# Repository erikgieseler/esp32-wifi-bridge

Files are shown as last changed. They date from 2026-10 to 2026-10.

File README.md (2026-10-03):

# ESP32-S3-POE-ETH WiFi–Ethernet SSL Bridge

Bridges your LAN to a Tesla Powerwall’s isolated Wi-Fi AP. Encrypted TLS is forwarded as-is (no decryption). TTL is set to 64 so the Powerwall sees local traffic.

Architecture

**Ethernet `:443`** — Powerwall passthrough (no login).  
**Ethernet `:80`** — dashboard (HTML login, username `admin`).  
Neither port is bound on the Tesla Wi-Fi address.

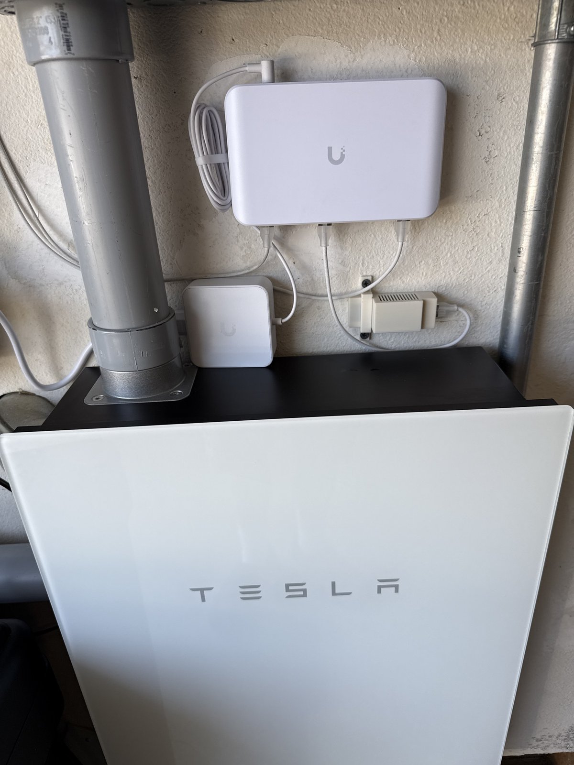
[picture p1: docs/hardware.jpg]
Installed next to a Tesla Powerwall


## Install

Browser flash (Chrome, Edge, or Opera) from GitHub Pages:

**https://erikgieseler.github.io/esp32-wifi-bridge/**

USB to the board, click **Install**. Tagged CI publishes `firmware.bin` and `version.json` there. Remote OTA uses the same URL. Enable **Settings → Pages → Deploy from a branch → `gh-pages`**. Forks do not need `config.local.h`.

After flash:

1. Plug Ethernet (PoE or USB power).
2. Open `http://powerwall.local/` or `http://<ethernet-ip>/`.
3. Set the admin password (first boot).
4. Save the Powerwall Wi-Fi SSID/password.
5. Optional: Ethernet tile → static IP.

Locked out: hold **BOOT 15 seconds** — forces DHCP and clears the admin password.

## Dashboard

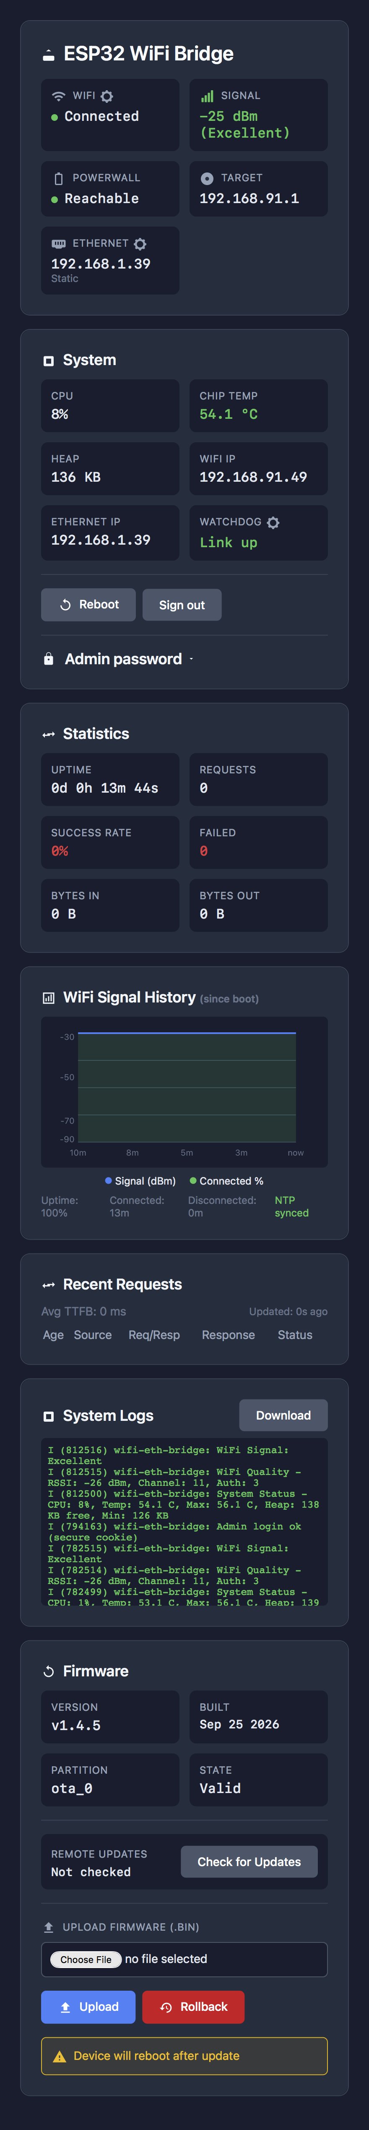
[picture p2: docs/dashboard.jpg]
Dashboard


- Wi-Fi RSSI and 24 h chart, Powerwall reachability
- Ethernet DHCP or static (click the Ethernet tile)
- CPU, chip temp, heap, uptime, proxy stats
- HTML login + 7-day session cookie (re-login after reboot/OTA)
- Download logs (last 200 lines, HAProxy `httpd*` noise omitted)
- Local upload or GitHub remote OTA

Put the dashboard behind TLS if you want HTTPS: HAProxy (or similar) to `:80`. Health checks should `GET /health` and expect **200**. Do not send a password; `/health` is unauthenticated on purpose.

## Hardware

| | |
|---|---|
| Board | Waveshare ESP32-S3-POE-ETH |
| PHY | W5500 over SPI |
| Framework | ESP-IDF (PlatformIO `espressif32@6.9.0`) |

| SPI | GPIO |
|---|---|
| MISO | 12 |
| MOSI | 11 |
| SCLK | 13 |
| CS | 14 |
| INT | 10 |
| BOOT (hold 15 s) | 0 |

### Printed case

A snap-fit ASA enclosure (no supports) with a wall mount is in [`case/`](case/). Vents are meant for **horizontal** wall install so heat rises through the grille.

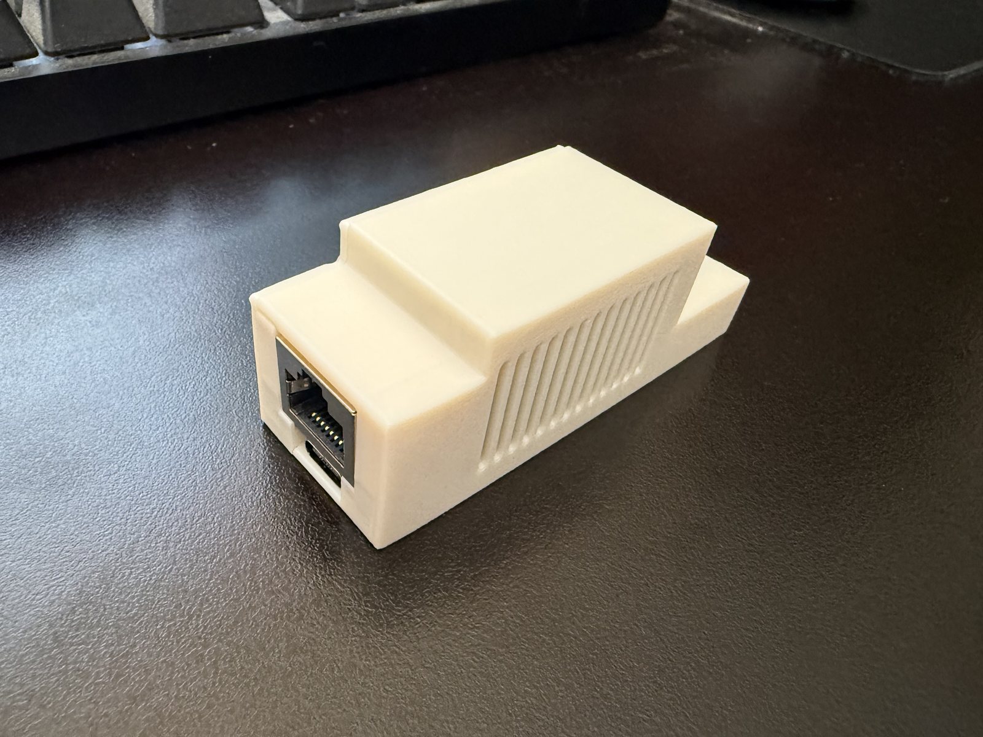
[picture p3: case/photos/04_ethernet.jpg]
Case


## Features

- SSL/TLS **passthrough** to `192.168.91.1:443` with **TTL 64**
- Ethernet **DHCP** or **static IP** (NVS); 45 s gateway-unreachable fallback to DHCP (saved static kept)
- HTTP and proxy **bound to the Ethernet IP only**
- mDNS `powerwall.local` (`_powerwall._tcp` :443, `_http._tcp` :80)
- Admin password: salted SHA-256 in NVS, HTML form, session cookie (`HttpOnly; SameSite=Lax`; `Secure` when `X-Forwarded-Proto: https`)
- Watchdog with two triggers (see below). Default is unchanged.
- NTP over Ethernet, OTA from GitHub Pages, Ethernet DNS snapshot so Wi-Fi cannot steal OTA DNS

## Reverse proxy (HAProxy)

```
backend esp32
    server esp32 192.168.1.39:80
    option httpchk
    http-check send meth GET uri /health
    http-check expect status 200
```

Send `X-Forwarded-Proto: https` on the TLS frontend so the session cookie is marked `Secure` (Safari will persist it). Check interval around 15–30 s is plenty.

## HTTP

Dashboard: `http://powerwall.local/` or `http://<eth-ip>/`  
First boot: set password. Later: **Username — admin**. Port 443 is not this login.

| Path | Auth | Notes |
|---|---|---|
| `GET /` | session | Dashboard |
| `GET/POST /login` | no | HTML login |
| `GET /logout` | no | Clears cookie |
| `GET /health` | no | `200 ok` for load balancers |
| `GET /logs.txt` | session | Downloadable log dump |
| `GET /api/status` | session | JSON (wifi, eth, temp, heap, watchdog) |
| `GET /api/requests` | session | Recent proxy requests |
| `GET /api/logs` | session | JSON log ring |
| `GET /api/wifi-history` | session | 24 h RSSI buckets |
| `GET /api/update` | session | Remote OTA status |
| `POST /api/check-update` | session | Check GitHub |
| `POST /api/install-update` | session | Install from GitHub |
| `GET /wifi/scan` | session | Scan SSIDs |
| `POST /wifi/save` | session | Save Wi-Fi |
| `POST /eth/save` | session | Save Ethernet (reboots) |
| `POST /watchdog/save` | session | `mode=proxy` or `mode=link` (no reboot) |
| `POST /admin/setup` | first boot | Set password |
| `POST /admin/password` | session | Change password |
| `POST /ota/upload` | session | Upload `.bin` |
| `POST /reboot` | session | Reboot |

Unauthenticated page requests redirect to `/login`. APIs return JSON `401`.

### Ethernet static IP

1. Dashboard → Ethernet tile → Static IP (address, mask, gateway, DNS).
2. Save (reboots).
3. If you lose it: wait ~45 s for DHCP fallback, or hold BOOT 15 s (also clears the admin password).

### Admin password

Stored as salt + SHA-256 in NVS, not in the firmware image. Change it from the System card (collapsed). Reboot/OTA drops RAM sessions; the cookie may still be in the browser until you sign in again.

### Watchdog

Click the **Watchdog** tile on the System card. Pick a trigger and **Save**. The device does not reboot. The choice is stored in NVS, survives OTA, and is not cleared by the 15-second BOOT hold.

| Trigger | When to use it | What it does |
|---|---|---|
| **Proxy clients** (default) | This bridge is the path clients use to reach the Powerwall | Stays **Idle** until the first successful proxy. Then reboots if no client completes a proxy for 10 minutes. |
| **Powerwall link** | Another path on the LAN reaches the gateway and this bridge is only a fallback | Ignores whether anyone is using the proxy. Reboots only if `192.168.91.1:443` stays unreachable for 10 minutes. |

The 10-minute clock in Powerwall link mode does not start until Wi-Fi has associated at least once, so boot is not treated as a failure. Reachability is a short TCP connect to `192.168.91.1:443` every **5 minutes** (not while the dashboard is merely refreshing). The tile keeps the last result. One extra check runs before a reboot, so a link that recovered is not reset by a stale failure. The tile shows **Link up**, or **Link down** with how long it has been down (yellow, then red, as it nears 10 minutes). If the Powerwall is actually off, the bridge will reboot about 10–15 minutes after it stops answering, then every 10 minutes until it answers again. A reboot cannot bring the gateway back. Proxy clients mode is unchanged: no probe unless the dashboard is open, and then about every 5 seconds.

Switching back to **Proxy clients** disarms the watchdog until the next successful proxy, so an old idle stretch does not reboot the device immediately.

## Configuration

Compile-time defaults live in [`include/config.h`](include/config.h). Runtime Wi-Fi, Ethernet IP, watchdog trigger, and the admin password are NVS (dashboard), not git.

OTA URL is derived from the GitHub remote at build time (`https://<owner>.github.io/<repo>/version.json`). Optional gitignored overrides: copy [`include/config.local.h.example`](include/config.local.h.example) to `include/config.local.h`.

```c
#define POWERWALL_IP_STR "192.168.91.1"
#define PROXY_PORT 443
#define PROXY_TIMEOUT_MS 60000
#define TTL_VALUE 64
#define ETH_DHCP_FALLBACK_SEC 45
```

## Build

```bash
pio run                    # build
pio run -t upload          # USB
pio device monitor         # serial
./deploy.sh                # OTA via mDNS
./deploy.sh -i <IP>        # OTA to one IP
```

Tags `v*` build firmware, GitHub Release, and Pages. Flash wear: OTA alternates `ota_0` / `ota_1`; NVS is not rewritten by OTA.

## Layout

| Path | Role |
|---|---|
| `src/main.c` | Ethernet/Wi-Fi, HTTP, auth, watchdog, log ring |
| `src/proxy.c` | TLS passthrough, buffer pool, request log |
| `src/remote_ota.c` | GitHub OTA, Ethernet DNS pin |
| `src/wifi_metrics.c` | NTP + 24 h RSSI history |
| `include/config.h` | Compile-time constants |
| `include/web_ui.h` | CSS / JS / icons |
| `partitions.csv` | nvs 24 KB, dual 1.75 MB OTA slots |
| `case/` | ASA enclosure STLs + print notes |

## License

Provided as-is for ESP32-S3-POE-ETH hardware. Fork of [cwagz/esp32-wifi-bridge](https://github.com/cwagz/esp32-wifi-bridge).

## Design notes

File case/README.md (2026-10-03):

# 3D-printed enclosure

Snap-fit case for the **Waveshare ESP32-S3-POE-ETH** (board + PoE hat). Designed to hang **horizontally** on the wall next to a Tesla Powerwall. Vents are placed so hot air rises and draws cool air through the shell.

ASA, **no supports**.

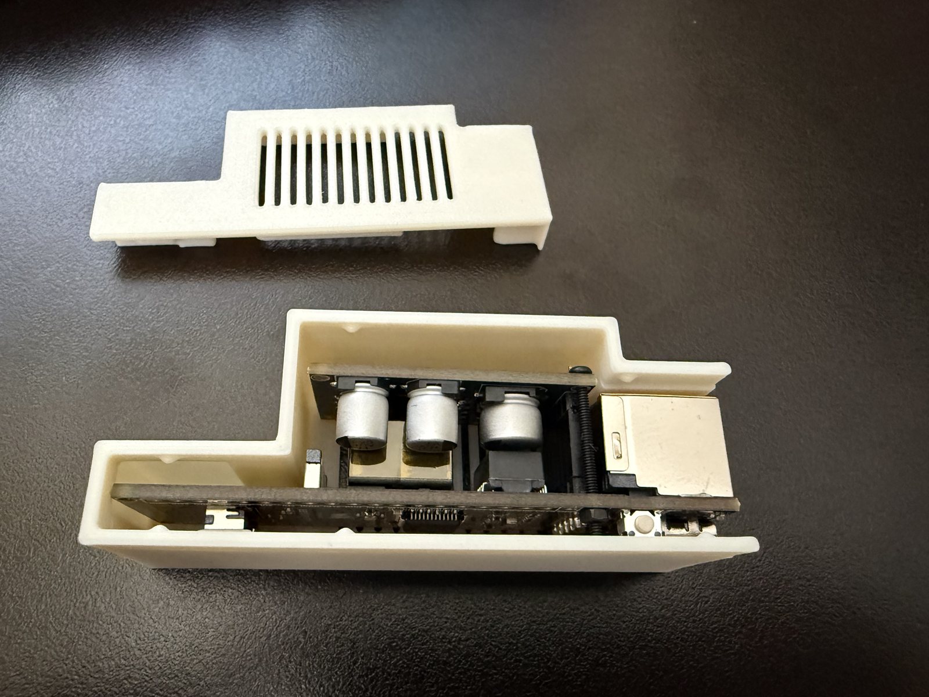
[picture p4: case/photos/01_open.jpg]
Open case with board

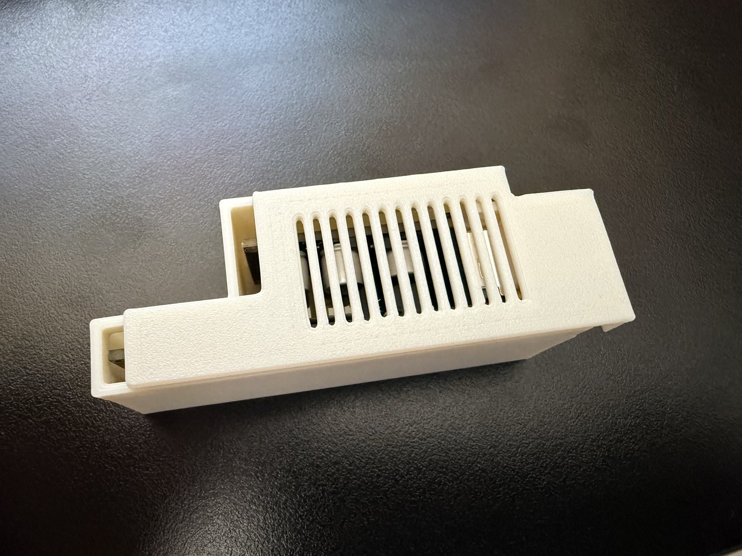
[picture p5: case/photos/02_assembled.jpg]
Assembled, vents


## Parts

| File | What |
|---|---|
| [esp32_BTM.stl](esp32_BTM.stl) | Bottom shell (board sits here) |
| [esp32_TOP.stl](esp32_TOP.stl) | Lid — slides **left** to snap shut |
| [esp32_MOUNT.stl](esp32_MOUNT.stl) | Wall bracket, two screw holes |

Print one of each.

Ethernet / USB end
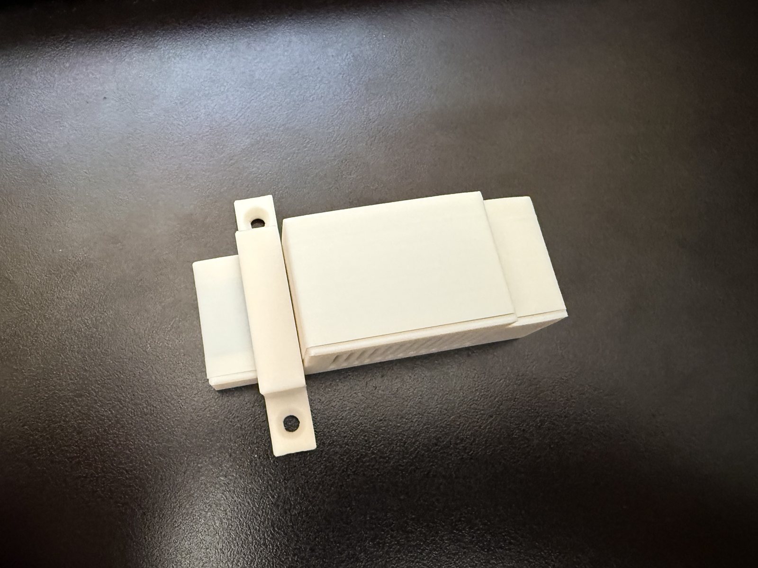
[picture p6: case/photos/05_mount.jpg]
Wall mount


## Print (ASA)

| Setting | Suggested |
|---|---|
| Material | **ASA** (PETG works; ASA is what this was proven on) |
| Supports | **None** |
| Layer | 0.2 mm |
| Walls | 4 |
| Infill | 15% |
| Chamber | Enclosed printer recommended for ASA (warping) |

Keep the large flat faces on the bed.

## Assembly

1. Seat the ESP32-S3-POE-ETH (with PoE hat) in the **bottom**. RJ45 and USB-C face the open end.
2. Drop the **lid** on and **slide it left** until it snaps. Do not force it straight down.
3. Clip or screw the **mount** onto the back, then hang the whole unit **horizontally** so the vent grille is on the **top** face.

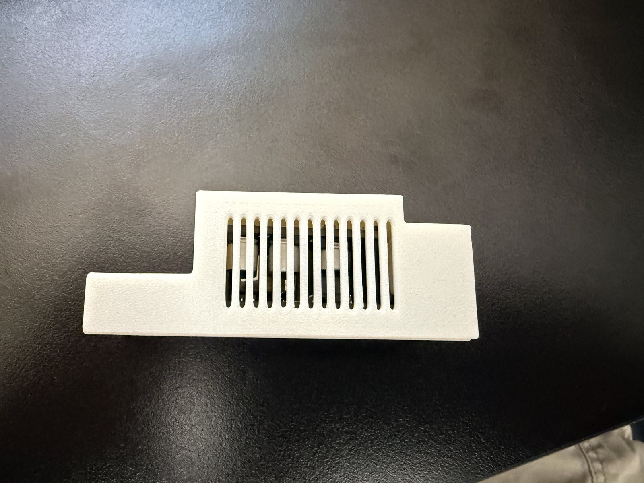
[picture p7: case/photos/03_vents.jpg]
Vent grille (top when wall-mounted)


Horizontal wall mount is required for the convection path. Vertical mounting traps heat.

Ethernet and USB-C stay reachable. Slide the lid off to reach **BOOT** / **RESET** (hold BOOT 15 s to force DHCP and clear the admin password).

## Hardware

- Waveshare **ESP32-S3-POE-ETH**
- PoE on the hat (or USB-C for power only)
- Two wall screws for the mount (use anchors if you are going into drywall)

License: same as the firmware — provided as-is for this board.

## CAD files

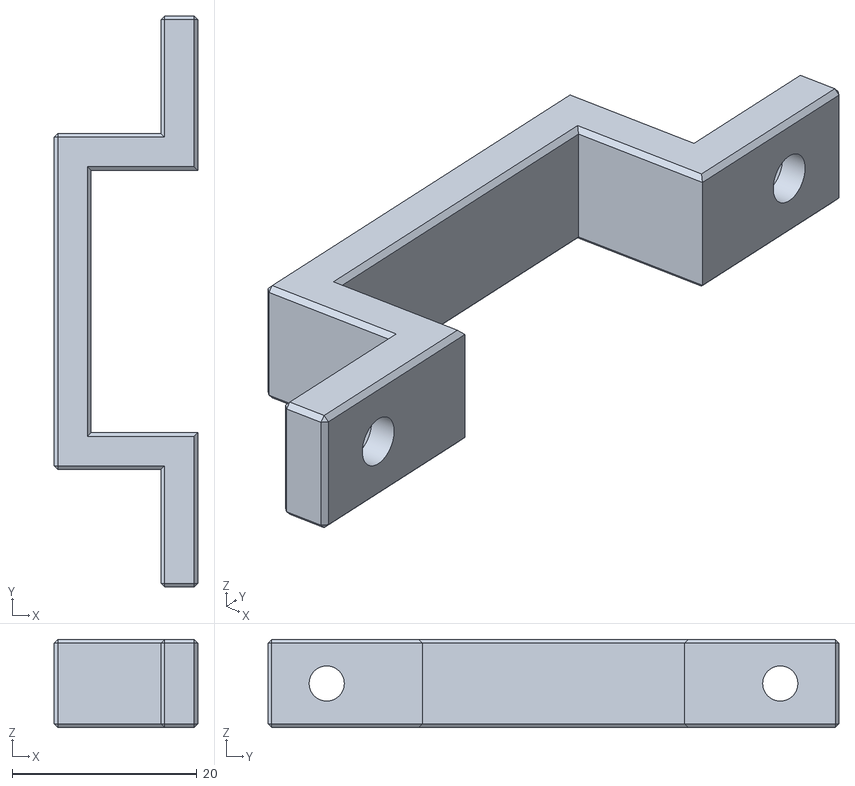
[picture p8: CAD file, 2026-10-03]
case/esp32_MOUNT.stl
15.6 x 61.7 x 9.53

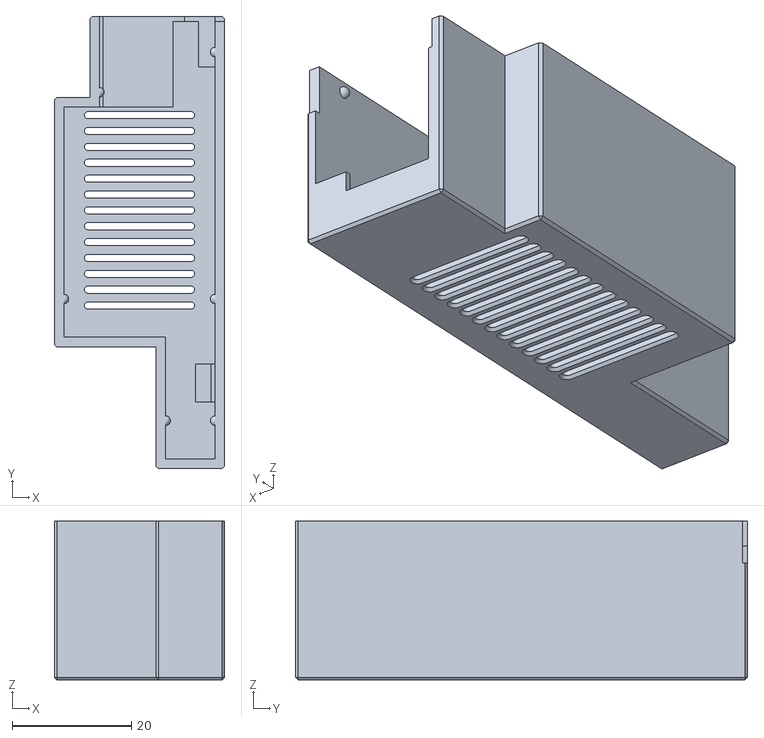
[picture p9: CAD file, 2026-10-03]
case/esp32_BTM.stl
28.5 x 75.7 x 26.6

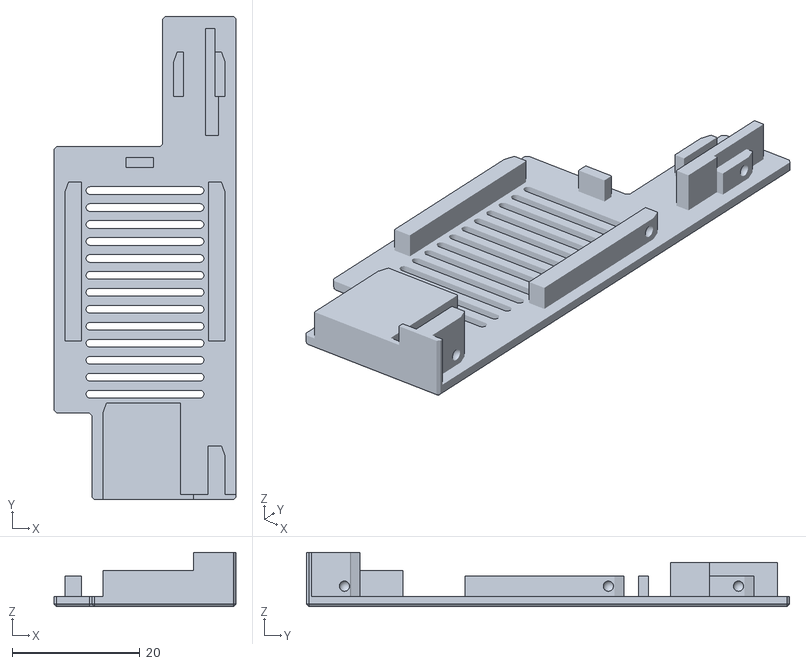
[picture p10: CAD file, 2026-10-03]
case/esp32_TOP.stl
28.5 x 75.7 x 8.50

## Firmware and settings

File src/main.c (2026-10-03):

/*
 * ESP32-S3 W5500 Ethernet WiFi Bridge (ESP-IDF)
 *
 * This implementation uses ESP-IDF native esp_eth driver with W5500 over SPI.
 * Implements SSL/TLS passthrough proxy without decryption.
 * The proxy forwards encrypted traffic from Ethernet to WiFi and modifies TTL to hide external origin.
 */

#include <string.h>
#include <strings.h>
#include <errno.h>
#include <fcntl.h>
#include <time.h>
#include "freertos/FreeRTOS.h"
#include "freertos/task.h"
#include "freertos/event_groups.h"
#include "freertos/semphr.h"
#include "esp_system.h"
#include "esp_mac.h"
#include "esp_wifi.h"
#include "esp_event.h"
#include "esp_log.h"
#include "esp_eth.h"
#include "esp_netif.h"
#include "nvs_flash.h"
#include "nvs.h"
#include "driver/gpio.h"
#include "driver/spi_master.h"
#include "mdns.h"
#include "lwip/err.h"
#include "lwip/sockets.h"
#include "lwip/sys.h"
#include "lwip/netdb.h"
#include "esp_ota_ops.h"
#include "esp_http_server.h"
#include "esp_app_format.h"
#include "esp_timer.h"
#include "driver/temperature_sensor.h"
#include "esp_http_client.h"
#include "esp_https_ota.h"
#include "esp_crt_bundle.h"
#include "esp_random.h"
#include "mbedtls/sha256.h"
#include "mbedtls/base64.h"

#include "config.h"
#include "web_ui.h"
#include "favicon_png.h"
#include "proxy.h"
#include "remote_ota.h"
#include "wifi_metrics.h"

static const char *TAG = "wifi-eth-bridge";

// NVS namespace for WiFi credentials
#define NVS_WIFI_NAMESPACE "wifi_config"
#define NVS_KEY_SSID "ssid"
#define NVS_KEY_PASSWORD "password"

// NVS namespace for Ethernet LAN settings
#define NVS_ETH_NAMESPACE "eth_config"
#define NVS_KEY_ETH_STATIC "static"
#define NVS_KEY_ETH_IP "ip"
#define NVS_KEY_ETH_MASK "mask"
#define NVS_KEY_ETH_GW "gw"
#define NVS_KEY_ETH_DNS "dns"
#define NVS_KEY_ETH_FORCE_DHCP "force_dhcp"
#define NVS_KEY_ETH_FELL_BACK "fell_back"

#define NVS_REBOOT_NAMESPACE "reboot"
#define NVS_KEY_REBOOT_INTERVAL "interval"

#define NVS_ADMIN_NAMESPACE "admin"
#define NVS_KEY_ADMIN_SALT "salt"
#define NVS_KEY_ADMIN_HASH "hash"
#define NVS_WD_NAMESPACE "watchdog"
#define NVS_KEY_WD_MODE "mode"
#define ADMIN_SALT_LEN 16
#define ADMIN_HASH_LEN 32

// WiFi credentials (runtime, loaded from NVS)
static char wifi_ssid[33] = "";
static char wifi_password[65] = "";
static bool wifi_configured = false;  // True if credentials saved in NVS

// Ethernet LAN configuration (runtime, loaded from NVS)
typedef struct {
    bool use_static;            // Saved preference: static vs DHCP
    bool using_fallback;        // This boot is on DHCP due to fallback/BOOT
    bool fell_back_last_boot;   // Sticky UI warning until the user saves
    char ip[16];
    char netmask[16];
    char gateway[16];
    char dns[16];
} eth_lan_config_t;

static eth_lan_config_t eth_cfg = {0};
static volatile bool eth_lan_confirmed = false;  // HTTP or proxy traffic seen

static uint8_t admin_salt[ADMIN_SALT_LEN];
static uint8_t admin_hash[ADMIN_HASH_LEN];
static bool admin_configured = false;

// Powerwall connectivity status
static volatile bool powerwall_reachable = false;
static volatile int64_t last_powerwall_check = 0;

// Boot time for uptime calculation
static int64_t boot_time_us = 0;

// Connection watchdog timestamp (proxy-clients mode)
static volatile int64_t last_successful_connection_time = 0;
// false = proxy clients (default). true = Powerwall link.
static volatile bool wd_link_mode = false;
static volatile bool wifi_was_up = false;
static volatile int64_t link_down_since_us = 0;

// Auto reboot interval (0 = disabled) – persisted in NVS "reboot"
static volatile uint32_t g_reboot_interval_sec = AUTO_REBOOT_INTERVAL_SEC;
static int64_t g_reboot_start_us = 0;

// Event group for WiFi and Ethernet status
static EventGroupHandle_t s_event_group;
#define WIFI_CONNECTED_BIT BIT0
#define ETH_CONNECTED_BIT BIT1
#define ETH_GOT_IP_BIT BIT2

// CPU usage tracking (percentage, 0-100)
static volatile uint8_t cpu_usage_percent = 0;

// On-die temperature (°C). chip_temp_ok is false until the first good sample.
static temperature_sensor_handle_t temp_handle = NULL;
static volatile float chip_temp_c = 0;
static volatile float chip_temp_max_c = 0;
static volatile bool chip_temp_ok = false;
static volatile bool chip_temp_max_ok = false;

// ===== Log Capture Ring Buffer =====
#define LOG_BUFFER_SIZE 200
#define LOG_MSG_MAX_LEN 160

typedef struct {
    int64_t timestamp;      // Seconds since boot
    uint8_t level;          // ESP_LOG_ERROR=1, WARN=2, INFO=3, DEBUG=4, VERBOSE=5
    char message[LOG_MSG_MAX_LEN];
} log_entry_t;

static log_entry_t log_buffer[LOG_BUFFER_SIZE];
static int log_buffer_index = 0;
static SemaphoreHandle_t log_mutex = NULL;
static vprintf_like_t original_vprintf = NULL;

static void log_sanitize(char *s)
{
    char *r = s, *w = s;
    while (*r) {
        if (*r == '\x1b' && r[1] == '[') {
            r += 2;
            while (*r && *r != 'm') {
                r++;
            }
            if (*r == 'm') {
                r++;
            }
            continue;
        }
        if (*r == '\r') {
            r++;
            continue;
        }
        if (*r == '\n' || *r == '\t') {
            if (w > s && w[-1] != ' ') {
                *w++ = ' ';
            }
            r++;
            continue;
        }
        *w++ = *r++;
    }
    while (w > s && w[-1] == ' ') {
        w--;
    }
    *w = '\0';
}

static bool log_is_httpd_noise(const char *s)
{
    const char *p = strchr(s, ')');
    if (!p || p[1] != ' ') {
        return s[0] == '\0';
    }
    p += 2;
    return strncmp(p, "httpd", 5) == 0;
}

/** Custom log handler to capture logs to ring buffer */
static int custom_log_vprintf(const char *fmt, va_list args)
{
    // Always call original handler first
    int ret = 0;
    if (original_vprintf) {
        va_list args_copy;
        va_copy(args_copy, args);
        ret = original_vprintf(fmt, args_copy);
        va_end(args_copy);
    }

    // Try to capture log (non-blocking to avoid deadlocks)
    if (log_mutex && xSemaphoreTake(log_mutex, 0) == pdTRUE) {
        char temp[LOG_MSG_MAX_LEN + 32];
        va_list args_copy;
        va_copy(args_copy, args);
        vsnprintf(temp, sizeof(temp), fmt, args_copy);
        va_end(args_copy);
        log_sanitize(temp);

        if (temp[0] == '\0' || log_is_httpd_noise(temp)) {
            xSemaphoreGive(log_mutex);
            return ret;
        }

        log_entry_t *entry = &log_buffer[log_buffer_index];
        entry->timestamp = esp_timer_get_time() / 1000000;

        entry->level = 3;
        if (temp[0] == 'E') entry->level = 1;
        else if (temp[0] == 'W') entry->level = 2;
        else if (temp[0] == 'I') entry->level = 3;
        else if (temp[0] == 'D') entry->level = 4;
        else if (temp[0] == 'V') entry->level = 5;

        strncpy(entry->message, temp, LOG_MSG_MAX_LEN - 1);
        entry->message[LOG_MSG_MAX_LEN - 1] = '\0';

        log_buffer_index = (log_buffer_index + 1) % LOG_BUFFER_SIZE;
        xSemaphoreGive(log_mutex);
    }

    return ret;
}

/** Initialize the log capture system */
static void init_log_capture(void)
{
    log_mutex = xSemaphoreCreateMutex();
    for (int i = 0; i < LOG_BUFFER_SIZE; i++) {
        log_buffer[i].timestamp = 0;
        log_buffer[i].level = 0;
        log_buffer[i].message[0] = '\0';
    }
    // Install custom log handler
    original_vprintf = esp_log_set_vprintf(custom_log_vprintf);
    ESP_LOGI(TAG, "Log capture initialized: %d entries", LOG_BUFFER_SIZE);
}

// Ethernet and WiFi handles
static esp_eth_handle_t eth_handle = NULL;
static esp_netif_t *eth_netif = NULL;
static esp_netif_t *wifi_netif = NULL;

// OTA HTTP server handle
static httpd_handle_t web_server = NULL;
static uint32_t http_listen_addr = 0;  // IPv4 the HTTP socket is bound to (0 = not bound)

// ===== NVS WiFi Credential Storage =====

/** Load WiFi credentials from NVS - returns true if credentials exist */
static bool load_wifi_credentials(void)
{
    nvs_handle_t nvs_handle;
    esp_err_t err = nvs_open(NVS_WIFI_NAMESPACE, NVS_READONLY, &nvs_handle);
    if (err != ESP_OK) {
        ESP_LOGI(TAG, "No saved WiFi credentials in NVS");
        wifi_configured = false;
        return false;
    }

    size_t ssid_len = sizeof(wifi_ssid);
    size_t pass_len = sizeof(wifi_password);

    err = nvs_get_str(nvs_handle, NVS_KEY_SSID, wifi_ssid, &ssid_len);
    if (err == ESP_OK) {
        err = nvs_get_str(nvs_handle, NVS_KEY_PASSWORD, wifi_password, &pass_len);
    }

    nvs_close(nvs_handle);

    if (err == ESP_OK && strlen(wifi_ssid) > 0) {
        ESP_LOGI(TAG, "Loaded WiFi credentials from NVS: SSID=%s", wifi_ssid);
        wifi_configured = true;
        return true;
    }

    ESP_LOGI(TAG, "No valid WiFi credentials found");
    wifi_configured = false;
    return false;
}

/** Save WiFi credentials to NVS */
static esp_err_t save_wifi_credentials(const char *ssid, const char *password)
{
    nvs_handle_t nvs_handle;
    esp_err_t err = nvs_open(NVS_WIFI_NAMESPACE, NVS_READWRITE, &nvs_handle);
    if (err != ESP_OK) {
        ESP_LOGE(TAG, "Failed to open NVS: %s", esp_err_to_name(err));
        return err;
    }

    err = nvs_set_str(nvs_handle, NVS_KEY_SSID, ssid);
    if (err == ESP_OK) {
        err = nvs_set_str(nvs_handle, NVS_KEY_PASSWORD, password);
    }
    if (err == ESP_OK) {
        err = nvs_commit(nvs_handle);
    }

    nvs_close(nvs_handle);

    if (err == ESP_OK) {
        ESP_LOGI(TAG, "WiFi credentials saved to NVS: SSID=%s", ssid);
        // Update runtime credentials
        strncpy(wifi_ssid, ssid, sizeof(wifi_ssid) - 1);
        wifi_ssid[sizeof(wifi_ssid) - 1] = '\0';
        strncpy(wifi_password, password, sizeof(wifi_password) - 1);
        wifi_password[sizeof(wifi_password) - 1] = '\0';
    } else {
        ESP_LOGE(TAG, "Failed to save WiFi credentials: %s", esp_err_to_name(err));
    }

    return err;
}

// ===== Ethernet LAN (static IP / DHCP fallback) =====

static int hex_nibble(char c)
{
    if (c >= '0' && c <= '9') return c - '0';
    if (c >= 'a' && c <= 'f') return c - 'a' + 10;
    if (c >= 'A' && c <= 'F') return c - 'A' + 10;
    return -1;
}

static void url_decode_inplace(char *s)
{
    char *r = s, *w = s;
    while (*r) {
        if (*r == '+') {
            *w++ = ' ';
            r++;
        } else if (*r == '%' && r[1] && r[2]) {
            int hi = hex_nibble(r[1]);
            int lo = hex_nibble(r[2]);
            if (hi >= 0 && lo >= 0) {
                *w++ = (char)((hi << 4) | lo);
                r += 3;
            } else {
                *w++ = *r++;
            }
        } else {
            *w++ = *r++;
        }
    }
    *w = '\0';
}

static bool form_get(const char *body, const char *key, char *out, size_t out_len)
{
    char pattern[40];
    snprintf(pattern, sizeof(pattern), "%s=", key);
    const char *start = strstr(body, pattern);
    if (!start) {
        if (out_len) out[0] = '\0';
        return false;
    }
    start += strlen(pattern);
    const char *end = strchr(start, '&');
    size_t len = end ? (size_t)(end - start) : strlen(start);
    if (len >= out_len) len = out_len - 1;
    memcpy(out, start, len);
    out[len] = '\0';
    url_decode_inplace(out);
    return true;
}

static bool hash_equal(const uint8_t *a, const uint8_t *b, size_t n)
{
    uint8_t diff = 0;
    for (size_t i = 0; i < n; i++) {
        diff |= (uint8_t)(a[i] ^ b[i]);
    }
    return diff == 0;
}

static void hash_admin_password(const char *password, const uint8_t salt[ADMIN_SALT_LEN],
                                uint8_t out[ADMIN_HASH_LEN])
{
    unsigned char buf[ADMIN_SALT_LEN + ADMIN_MAX_PASSWORD_LEN];
    size_t plen = strlen(password);
    if (plen > ADMIN_MAX_PASSWORD_LEN) plen = ADMIN_MAX_PASSWORD_LEN;
    memcpy(buf, salt, ADMIN_SALT_LEN);
    memcpy(buf + ADMIN_SALT_LEN, password, plen);
    mbedtls_sha256(buf, ADMIN_SALT_LEN + plen, out, 0);
    memset(buf, 0, sizeof(buf));
}

static void init_temp_sensor(void)
{
    temperature_sensor_config_t cfg = TEMPERATURE_SENSOR_CONFIG_DEFAULT(-10, 80);
    if (temperature_sensor_install(&cfg, &temp_handle) != ESP_OK) {
        ESP_LOGW(TAG, "Chip temperature sensor not available");
        temp_handle = NULL;
        return;
    }
    if (temperature_sensor_enable(temp_handle) != ESP_OK) {
        ESP_LOGW(TAG, "Failed to enable temperature sensor");
        temperature_sensor_uninstall(temp_handle);
        temp_handle = NULL;
        return;
    }
    ESP_LOGI(TAG, "Chip temperature sensor enabled");
}

static void sample_chip_temp(void)
{
    if (!temp_handle) {
        chip_temp_ok = false;
        return;
    }
    float t = 0;
    if (temperature_sensor_get_celsius(temp_handle, &t) == ESP_OK) {
        chip_temp_c = t;
        chip_temp_ok = true;
        if (!chip_temp_max_ok || t > chip_temp_max_c) {
            chip_temp_max_c = t;
            chip_temp_max_ok = true;
        }
    }
}

static const char *chip_temp_color(void)
{
    if (!chip_temp_ok) {
        return "#94a3b8";
    }
    if (chip_temp_c >= 80.0f) {
        return "#ef4444";
    }
    if (chip_temp_c >= 65.0f) {
        return "#eab308";
    }
    return "#22c55e";
}

static void load_admin_config(void)
{
    memset(admin_salt, 0, sizeof(admin_salt));
    memset(admin_hash, 0, sizeof(admin_hash));
    admin_configured = false;

    nvs_handle_t h;
    if (nvs_open(NVS_ADMIN_NAMESPACE, NVS_READONLY, &h) != ESP_OK) {
        ESP_LOGI(TAG, "No admin password set - first-boot setup required");
        return;
    }

    size_t salt_len = ADMIN_SALT_LEN;
    size_t hash_len = ADMIN_HASH_LEN;
    esp_err_t salt_err = nvs_get_blob(h, NVS_KEY_ADMIN_SALT, admin_salt, &salt_len);
    esp_err_t hash_err = nvs_get_blob(h, NVS_KEY_ADMIN_HASH, admin_hash, &hash_len);
    nvs_close(h);

    if (salt_err == ESP_OK && hash_err == ESP_OK &&
        salt_len == ADMIN_SALT_LEN && hash_len == ADMIN_HASH_LEN) {
        admin_configured = true;
        ESP_LOGI(TAG, "Admin password is configured");
    } else {
        ESP_LOGI(TAG, "No admin password set - first-boot setup required");
    }
}

#define SESSION_COUNT 4
#define SESSION_ID_LEN 16
#define SESSION_IDLE_US (7LL * 24 * 3600 * 1000000)
#define SESSION_COOKIE_MAX_AGE 604800
#define SESSION_COOKIE_NAME "sid"

typedef struct {
    bool used;
    uint8_t id[SESSION_ID_LEN];
    int64_t last_us;
} admin_session_t;

static admin_session_t sessions[SESSION_COUNT];

static void session_clear_all(void)
{
    memset(sessions, 0, sizeof(sessions));
}

static void bytes_to_hex(const uint8_t *in, size_t n, char *out)
{
    static const char *h = "0123456789abcdef";
    for (size_t i = 0; i < n; i++) {
        out[i * 2] = h[in[i] >> 4];
        out[i * 2 + 1] = h[in[i] & 0xf];
    }
    out[n * 2] = '\0';
}

static bool hex_to_bytes(const char *s, uint8_t *out, size_t n)
{
    if (!s || strlen(s) != n * 2) return false;
    for (size_t i = 0; i < n; i++) {
        unsigned v = 0;
        for (int k = 0; k < 2; k++) {
            char c = s[i * 2 + k];
            v <<= 4;
            if (c >= '0' && c <= '9') v |= (unsigned)(c - '0');
            else if (c >= 'a' && c <= 'f') v |= (unsigned)(c - 'a' + 10);
            else if (c >= 'A' && c <= 'F') v |= (unsigned)(c - 'A' + 10);
            else return false;
        }
        out[i] = (uint8_t)v;
    }
    return true;
}

static bool session_create(char hex_out[SESSION_ID_LEN * 2 + 1])
{
    int slot = 0;
    int64_t now = esp_timer_get_time();
    int64_t oldest = sessions[0].last_us;
    for (int i = 0; i < SESSION_COUNT; i++) {
        if (!sessions[i].used || now - sessions[i].last_us > SESSION_IDLE_US) {
            slot = i;
            break;
        }
        if (sessions[i].last_us < oldest) {
            oldest = sessions[i].last_us;
            slot = i;
        }
    }
    esp_fill_random(sessions[slot].id, SESSION_ID_LEN);
    sessions[slot].used = true;
    sessions[slot].last_us = now;
    bytes_to_hex(sessions[slot].id, SESSION_ID_LEN, hex_out);
    return true;
}

static bool session_touch(const char *hex)
{
    uint8_t id[SESSION_ID_LEN];
    if (!hex_to_bytes(hex, id, SESSION_ID_LEN)) return false;
    int64_t now = esp_timer_get_time();
    for (int i = 0; i < SESSION_COUNT; i++) {
        if (!sessions[i].used) continue;
        if (now - sessions[i].last_us > SESSION_IDLE_US) {
            sessions[i].used = false;
            continue;
        }
        if (hash_equal(sessions[i].id, id, SESSION_ID_LEN)) {
            sessions[i].last_us = now;
            return true;
        }
    }
    return false;
}

static void session_drop(const char *hex)
{
    uint8_t id[SESSION_ID_LEN];
    if (!hex_to_bytes(hex, id, SESSION_ID_LEN)) return;
    for (int i = 0; i < SESSION_COUNT; i++) {
        if (sessions[i].used && hash_equal(sessions[i].id, id, SESSION_ID_LEN)) {
            sessions[i].used = false;
            memset(sessions[i].id, 0, SESSION_ID_LEN);
        }
    }
}

static bool request_is_https(httpd_req_t *req)
{
    char proto[16] = {0};
    if (httpd_req_get_hdr_value_str(req, "X-Forwarded-Proto", proto, sizeof(proto)) != ESP_OK) {
        return false;
    }
    return strcasecmp(proto, "https") == 0;
}

static void cookie_expires_gmt(char *out, size_t len, int offset_sec)
{
    time_t now = time(NULL);
    if (now < 1700000000 || !out || len < 32) {
        if (out && len) {
            out[0] = '\0';
        }
        return;
    }
    time_t exp = now + offset_sec;
    struct tm tm;
    gmtime_r(&exp, &tm);
    strftime(out, len, "%a, %d %b %Y %H:%M:%S GMT", &tm);
}

static void session_cookie_set(char *buf, size_t len, const char *hex, httpd_req_t *req)
{
    char exp[40] = {0};
    cookie_expires_gmt(exp, sizeof(exp), SESSION_COOKIE_MAX_AGE);
    snprintf(buf, len,
             SESSION_COOKIE_NAME "=%s; Path=/; HttpOnly; SameSite=Lax; Max-Age=%d%s%s%s",
             hex, SESSION_COOKIE_MAX_AGE,
             exp[0] ? "; Expires=" : "", exp,
             request_is_https(req) ? "; Secure" : "");
}

static void session_cookie_clear(char *buf, size_t len, httpd_req_t *req)
{
    snprintf(buf, len,
             SESSION_COOKIE_NAME "=; Path=/; HttpOnly; SameSite=Lax; Max-Age=0"
             "; Expires=Thu, 01 Jan 1970 00:00:00 GMT%s",
             request_is_https(req) ? "; Secure" : "");
}
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
void app_main(void)
{
    // Record boot time for uptime calculation
    boot_time_us = esp_timer_get_time();

    // Initialize log capture early to capture startup logs
    init_log_capture();

    ESP_LOGI(TAG, "=== ESP32-S3-POE-ETH WiFi-Ethernet SSL Bridge ===");
    ESP_LOGI(TAG, "Mode: SSL Passthrough (no decryption, TTL modification)");
    ESP_LOGI(TAG, "Target: Tesla Powerwall at %s:443", POWERWALL_IP_STR);

    // Print firmware version
    const esp_app_desc_t *app_desc = esp_app_get_description();
    ESP_LOGI(TAG, "Firmware version: %s (built %s %s)", app_desc->version, app_desc->date, app_desc->time);

    // Initialize NVS
    esp_err_t ret = nvs_flash_init();
    if (ret == ESP_ERR_NVS_NO_FREE_PAGES || ret == ESP_ERR_NVS_NEW_VERSION_FOUND) {
        ESP_ERROR_CHECK(nvs_flash_erase());
        ret = nvs_flash_init();
    }
    ESP_ERROR_CHECK(ret);

    load_admin_config();
    load_reboot_config();
    init_temp_sensor();
    sample_chip_temp();

    // Initialize Ethernet first (OTA server runs on Ethernet)
    ESP_ERROR_CHECK(init_ethernet());

    // Initialize WiFi (starts connection attempt in background)
    ESP_ERROR_CHECK(init_wifi());

    // Wait for Ethernet to get IP before starting OTA server
    ESP_LOGI(TAG, "Waiting for Ethernet IP...");
    EventBits_t ip_bits = xEventGroupWaitBits(s_event_group, ETH_GOT_IP_BIT, pdFALSE, pdTRUE,
                                              pdMS_TO_TICKS(15000));
    if ((ip_bits & ETH_GOT_IP_BIT) == 0) {
        esp_netif_ip_info_t assigned;
        if (eth_netif && esp_netif_get_ip_info(eth_netif, &assigned) == ESP_OK && assigned.ip.addr != 0) {
            ESP_LOGW(TAG, "GOT_IP event missed; using " IPSTR, IP2STR(&assigned.ip));
            xEventGroupSetBits(s_event_group, ETH_GOT_IP_BIT);
        } else {
            ESP_LOGI(TAG, "Still waiting for DHCP lease...");
            xEventGroupWaitBits(s_event_group, ETH_GOT_IP_BIT, pdFALSE, pdTRUE, portMAX_DELAY);
        }
    }

    // Initialize modules that depend on Ethernet
    remote_ota_init(eth_netif);
    proxy_init(s_event_group, ETH_GOT_IP_BIT, &last_successful_connection_time, eth_netif);
    wifi_metrics_init(s_event_group, WIFI_CONNECTED_BIT, eth_netif);

    // Start HTTP server on Ethernet (open_fn rejects sessions whose local IP is WiFi)
    start_http_server();
    ESP_LOGI(TAG, "HTTP server started - http://<eth-ip>/");

    // Initialize mDNS on Ethernet (for device discovery, doesn't need WiFi)
    init_mdns();

    // Validate OTA image early so device doesn't rollback while user configures WiFi
    validate_ota_image();

    // Static-IP DHCP fallback + BOOT-button recovery
    xTaskCreate(eth_dhcp_fallback_task, "eth_fallback", 3072, NULL, 3, NULL);
    xTaskCreate(eth_boot_button_task, "eth_boot_btn", 4096, NULL, 3, NULL);

    // Start system monitoring task
    xTaskCreate(system_monitor_task, "sys_monitor", 3072, NULL, 3, NULL);

    // Start connection watchdog task
    xTaskCreate(connection_watchdog_task, "conn_watchdog", 4096, NULL, 3, NULL);

    // Auto reboot by interval
    xTaskCreate(auto_reboot_task, "auto_reboot", 2048, NULL, 3, NULL);

    // Start WiFi-dependent services in background task
    // This allows OTA to remain responsive while waiting for WiFi
    xTaskCreate(wifi_services_task, "wifi_services", 4096, NULL, 4, NULL);

    ESP_LOGI(TAG, "System initialized - configure WiFi via OTA UI if needed");
}

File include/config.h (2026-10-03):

#ifndef CONFIG_H
#define CONFIG_H

/*
 * Optional local overrides — not tracked in git, and not required for GitHub forks:
 *   cp include/config.local.h.example include/config.local.h
 *
 * Remote OTA URL precedence (highest wins):
 *   CI env REMOTE_OTA_VERSION_URL
 *   config.local.h
 *   git origin → https://<owner>.github.io/<repo>/version.json
 *   default below
 */

#if defined(__has_include)
#  if __has_include("config.local.h")
#    include "config.local.h"
#  endif
#endif

// ===== WiFi Configuration =====
// Configure these to match your Tesla Powerwall WiFi network
#ifndef WIFI_SSID
#define WIFI_SSID "TeslaPowerwall"
#endif
#ifndef WIFI_PASSWORD
#define WIFI_PASSWORD ""
#endif

// Powerwall IP address on the WiFi network
#ifndef POWERWALL_IP_ADDR1
#define POWERWALL_IP_ADDR1 192
#endif
#ifndef POWERWALL_IP_ADDR2
#define POWERWALL_IP_ADDR2 168
#endif
#ifndef POWERWALL_IP_ADDR3
#define POWERWALL_IP_ADDR3 91
#endif
#ifndef POWERWALL_IP_ADDR4
#define POWERWALL_IP_ADDR4 1
#endif
#ifndef POWERWALL_IP_STR
#define POWERWALL_IP_STR "192.168.91.1"
#endif

// ===== W5500 SPI Pin Configuration =====
// These are the correct pins for ESP32-S3-POE-ETH (Waveshare)
#ifndef W5500_INT_GPIO
#define W5500_INT_GPIO  10
#endif
#ifndef W5500_MISO_GPIO
#define W5500_MISO_GPIO 12
#endif
#ifndef W5500_MOSI_GPIO
#define W5500_MOSI_GPIO 11
#endif
#ifndef W5500_SCK_GPIO
#define W5500_SCK_GPIO  13
#endif
#ifndef W5500_CS_GPIO
#define W5500_CS_GPIO   14
#endif

// ===== Ethernet IP Configuration =====
// If a static IP is saved but the LAN looks unreachable (no HTTP/proxy traffic
// and the gateway does not answer ICMP) for this many seconds after link-up,
// reboot into DHCP. Saved static settings are kept; the dashboard shows a warning.
#ifndef ETH_DHCP_FALLBACK_SEC
#define ETH_DHCP_FALLBACK_SEC 45
#endif
#ifndef ETH_DHCP_FALLBACK_PING_INTERVAL_MS
#define ETH_DHCP_FALLBACK_PING_INTERVAL_MS 3000
#endif
// Hold BOOT (GPIO0) this long after the firmware is running to force DHCP
// and clear the admin password. Long enough that a bump will not trigger it.
#ifndef ETH_BOOT_GPIO
#define ETH_BOOT_GPIO 0
#endif
#ifndef ETH_BOOT_HOLD_SEC
#define ETH_BOOT_HOLD_SEC 15
#endif
#ifndef ETH_BOOT_POLL_MS
#define ETH_BOOT_POLL_MS 100
#endif

// ===== Proxy Server Configuration =====
#ifndef PROXY_PORT
#define PROXY_PORT 443
#endif
#ifndef PROXY_TIMEOUT_MS
#define PROXY_TIMEOUT_MS 60000  // 60 seconds (increased from 30)
#endif
#ifndef PROXY_BUFFER_SIZE
#define PROXY_BUFFER_SIZE 4096  // Buffer size for forwarding encrypted data (larger = fewer syscalls)
#endif
#ifndef SSL_PASSTHROUGH_TASK_STACK_SIZE
#define SSL_PASSTHROUGH_TASK_STACK_SIZE 6144  // Stack size per client task (reduced from 8192)
#endif
#ifndef MAX_CONCURRENT_CLIENTS
#define MAX_CONCURRENT_CLIENTS 4  // Maximum simultaneous proxy connections (each uses 2 buffers)
#endif

// ===== TTL Configuration =====
// TTL (Time-To-Live) value to set on outgoing packets to hide external origin
// Common TTL values: 64 (Linux/Unix default), 128 (Windows default), 255 (Cisco default)
// Setting to 64 as it's the most common default for web servers
#ifndef TTL_VALUE
#define TTL_VALUE 64
#endif

// ===== mDNS Configuration =====
#ifndef MDNS_HOSTNAME
#define MDNS_HOSTNAME "powerwall"
#endif
#ifndef MDNS_SERVICE
#define MDNS_SERVICE "_powerwall"
#endif
#ifndef MDNS_PROTOCOL
#define MDNS_PROTOCOL "_tcp"
#endif

// ===== WiFi Quality Monitoring =====
// Interval for logging WiFi connection quality (in seconds)
#ifndef WIFI_QUALITY_LOG_INTERVAL_SEC
#define WIFI_QUALITY_LOG_INTERVAL_SEC 30  // Log every 30 seconds
#endif

// ===== System Monitoring =====
// Interval for logging system metrics (CPU load, etc.) in seconds
#ifndef SYSTEM_MONITOR_INTERVAL_SEC
#define SYSTEM_MONITOR_INTERVAL_SEC 30  // Log every 30 seconds
#endif

// ===== Connection Watchdog =====
// Proxy-clients mode: reboot if no successful proxy within this time (after the first one).
// Powerwall-link mode: reboot if the Powerwall stays unreachable for this long.
#ifndef WATCHDOG_TIMEOUT_SEC
#define WATCHDOG_TIMEOUT_SEC 600  // 10 minutes
#endif
#ifndef WATCHDOG_CHECK_INTERVAL_SEC
#define WATCHDOG_CHECK_INTERVAL_SEC 60  // Check every minute
#endif
// Powerwall-link mode only. TCP probe of 192.168.91.1:443.
// Dashboard refresh reuses the last result until this age.
#ifndef WATCHDOG_LINK_PROBE_SEC
#define WATCHDOG_LINK_PROBE_SEC 300  // 5 minutes
#endif

// ===== Auto Reboot (interval) =====
// Periodic reboot every N seconds (0 = disabled). GUI: hours input (0 = off)
#ifndef AUTO_REBOOT_INTERVAL_SEC
#define AUTO_REBOOT_INTERVAL_SEC 0
#endif
#ifndef AUTO_REBOOT_CHECK_INTERVAL_SEC
#define AUTO_REBOOT_CHECK_INTERVAL_SEC 60
#endif

// ===== Debug Configuration =====
// Enable DEBUG_MODE to show encrypted packet forwarding details
#ifndef DEBUG_MODE
#define DEBUG_MODE 0  // Set to 1 to enable debug logging
#endif
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
